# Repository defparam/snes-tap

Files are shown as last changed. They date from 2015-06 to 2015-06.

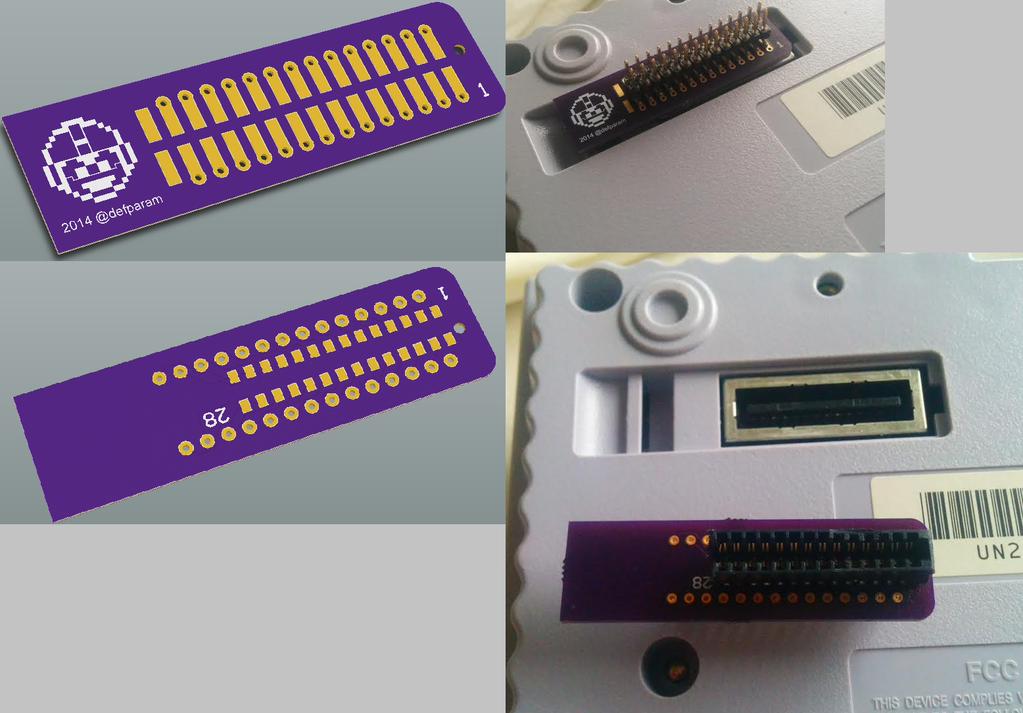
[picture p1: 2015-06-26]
photos/model_v1.0_revA.jpg

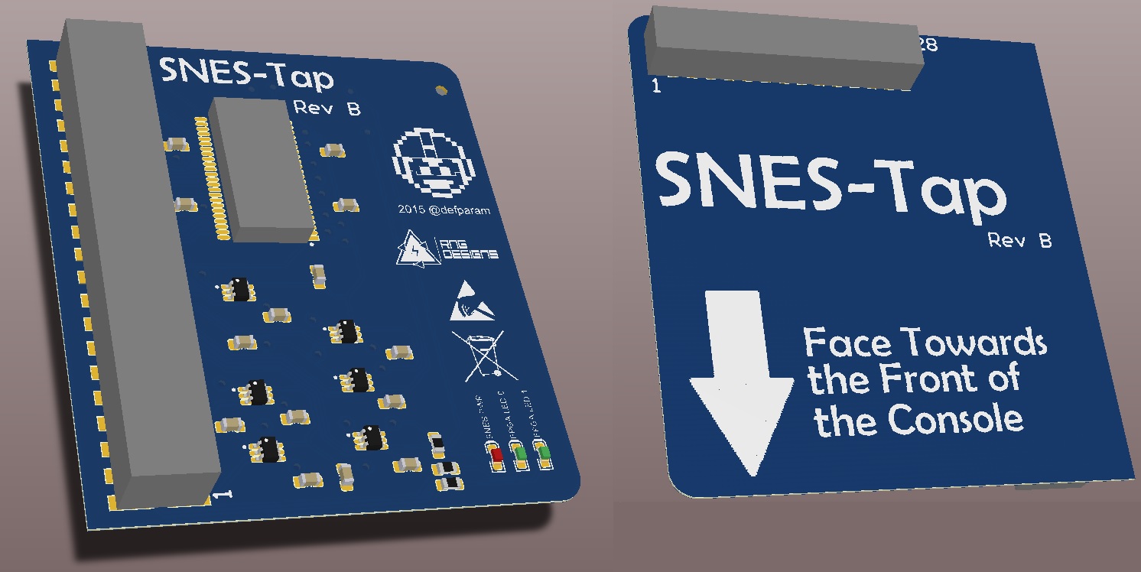
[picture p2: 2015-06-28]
photos/model_v1.2_revB.jpg

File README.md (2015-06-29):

# SNES-Tap
This project includes Altium design files for an SNES expansion port tapping board to enable FPGA snooping of the SNES console.

SNES-Tap v1.2 Rev B
---------------------------------------------------------------------
This is the second major release of this project. Drastic changes have
been made to allow for on board voltage translation support. The board
geometries have been modified to accommodate the active components and 
to interface to a 40-PIN 100mil header (instead of 30-pin in Rev A). 
The pinout of this header conforms with the GPIO 40-pin header of the 
Terasic DE0-Nano and DE0-Nano-SoC FPGA dev boards. Zipped up gerber/drill 
files have been submitted for easy fabrication direct to OSHPark 
without any DRC issues. Also included PDF schematic/layout and a 3D image
model of the board to be fabbed.

Order the board direct from OSHPark here: https://oshpark.com/shared_projects/csoqiSJ5

SNES-Tap v1.0 Rev A
---------------------------------------------------------------------
This inital version of the board design files describes a simple adapter
board that converts the SNES bottom expansion port interface to a standard
100 mil IDC header for hardware interfacing. This interface gives you access
to the data bus and the peripheral address bus of the SNES. The interface also
gives you access to analog audio channels, the reset, the interrupt pin and a
couple of clocks.

Order the board direct from OSHPark here: https://oshpark.com/shared_projects/HncHwJox

Components (Connectors)
---------------------------------------------------------------------
There are two connectors used in this board. The connector which plugs into the SNES
expansion port is a rare 2.0mm pitch micro edge connector. There aren't many vendors
which create this connector type. On this board we use the SAMTEC MEC2-30-01-L-DV.
The MEC2-30-01-L-DV is a 60-pin polarized connector, since the MEC2 doesn't have a 28-pin
variant we use the MEC2-30-01-L-DV and saw/dremel off pins 29-60. The footprint in the design
is modified to adapt to this new 28-pin footprint.

The second connector is a simple 30-pin 100 mil IDC header. In this design we used the
SAMTEC TSM-114-01-L-DV. (REV A only)

On Rev B the pin header will be 40-pin 100 mil IDC header. The part number is SAMTEC HTST-120-01-T-DV

TODO:
--------
Assemble the board, fix issues and incorporate fixed into v1.4 Rev C

-Evan

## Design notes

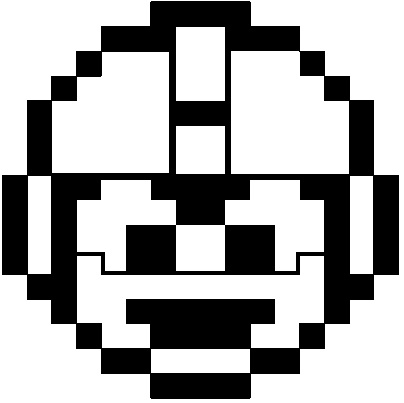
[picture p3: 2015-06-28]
photos/helmet.jpg

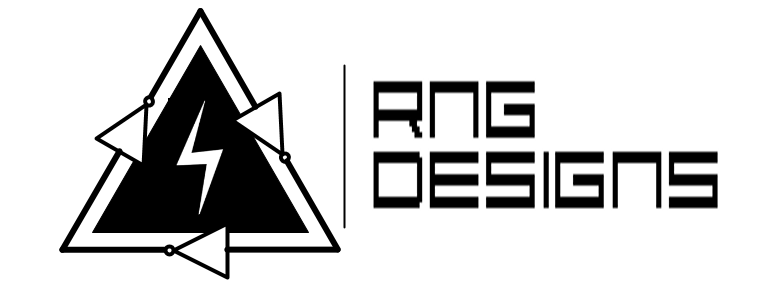
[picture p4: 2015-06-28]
photos/rngd.bmp

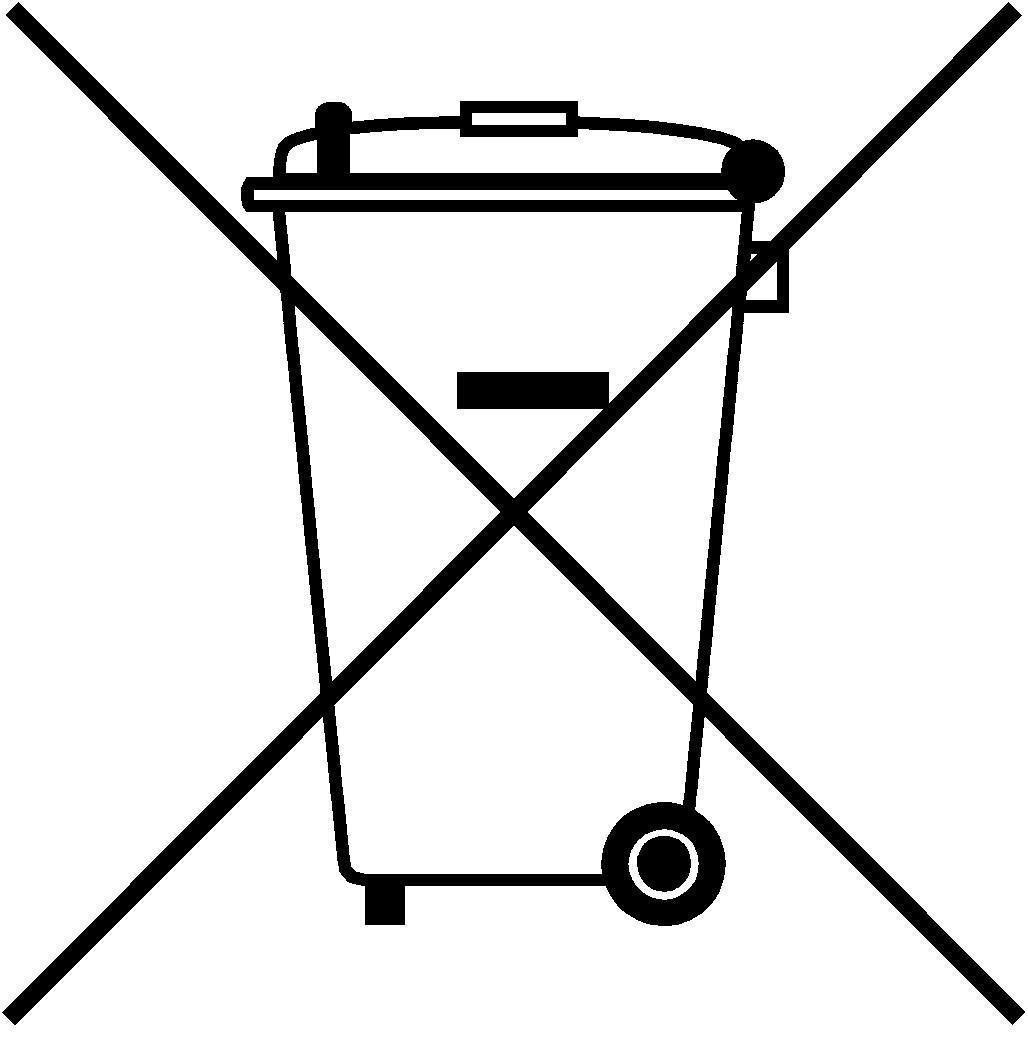
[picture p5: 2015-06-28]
photos/weee.bmp

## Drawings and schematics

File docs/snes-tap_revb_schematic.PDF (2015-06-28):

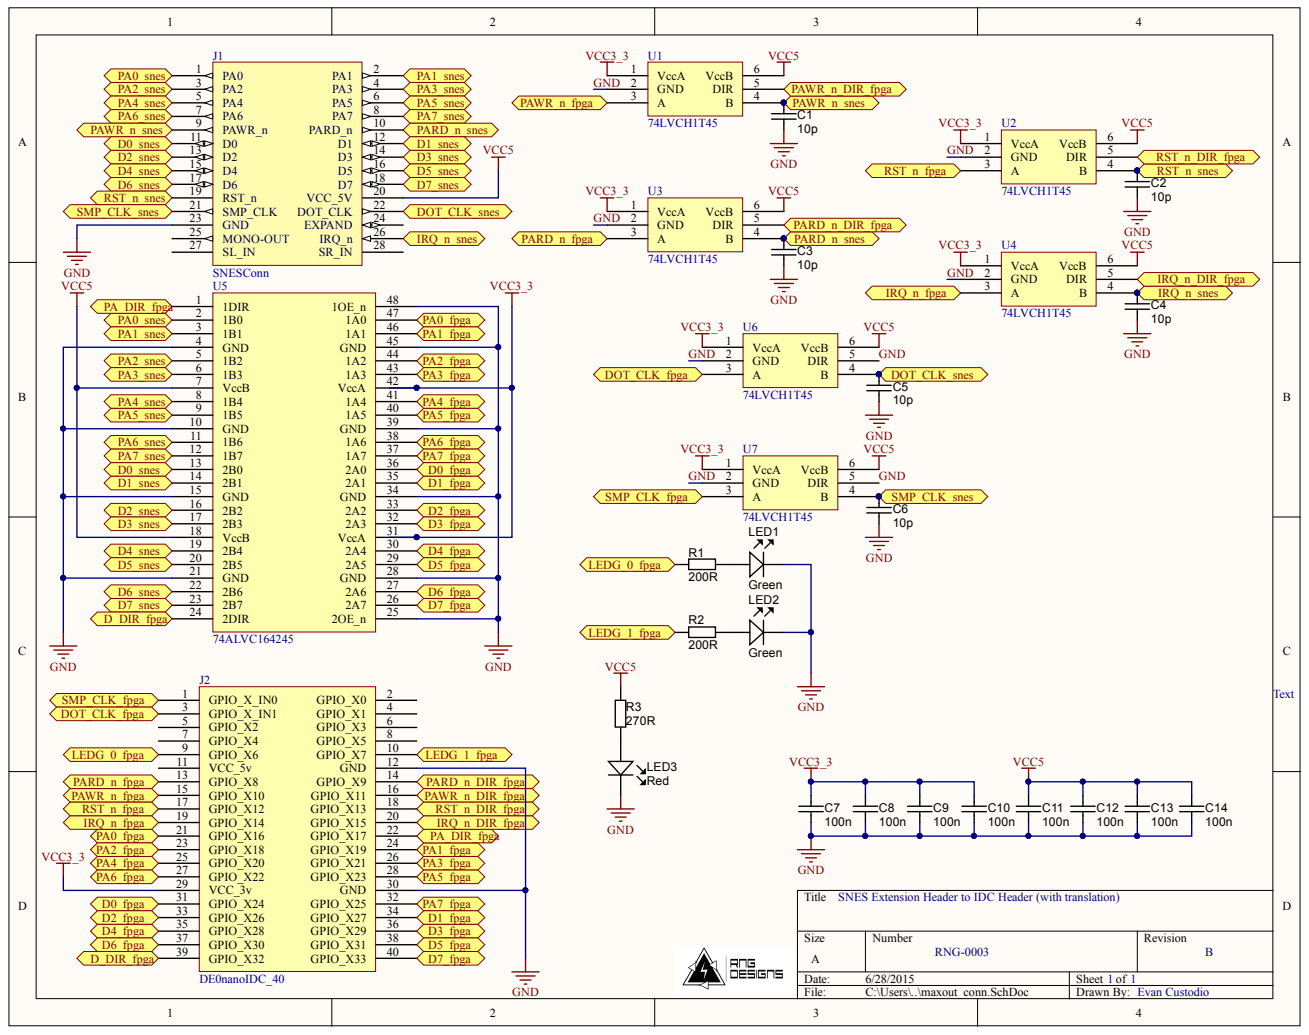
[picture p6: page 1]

1B5 9 | 25 2A7 26 2A6 27 GND 28 2A5 29 2A4 30 VccA 31 2A3 32 2A2 33 GND 34 2A1 35 2A0 36 1A7 37 1A6 38 GND 39 1A5 40 1A4 41 VccA 42 1A3 43 1A2 44 GND 45 1A1 46 1A0 47 1OE_n

PA6_snes PA7_snes D0_snes D1_snes | 1B6 11 | PA6_fpga PA7_fpga D0_fpga D1_fpga

SNES Extension Header to IDC Header (with translation)

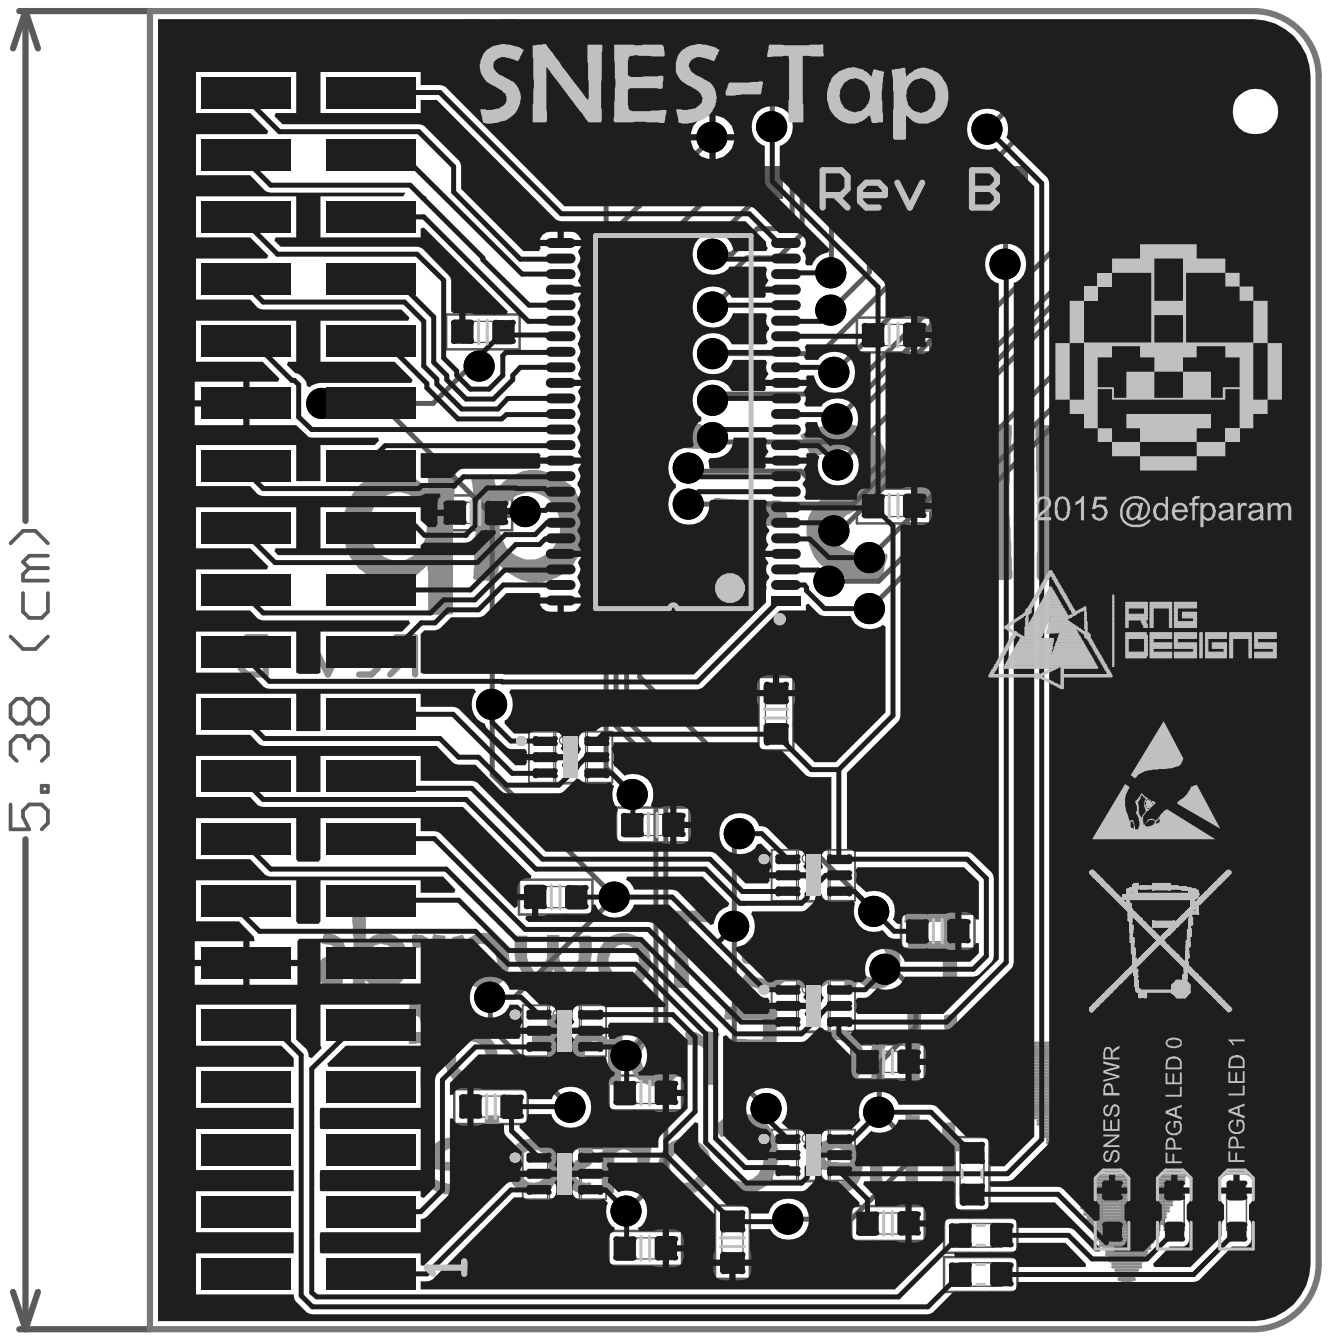
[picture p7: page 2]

# Board S

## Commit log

2015-06-26 initial checkin v1.0
    This is the initial checkin on the snes-tap board
    [SNESConn.PcbLib, SNESConn.SchLib, SNESConnIDC.PcbLib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]
2015-06-26 Revert "initial checkin v1.0"
    This reverts commit ad7a35833748aa7cc485e4c0c2509bb23b4a8a90.
    [SNESConn.PcbLib, SNESConn.SchLib, SNESConnIDC.PcbLib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]
2015-06-26 Initial Checkin
    [SNESConn.PcbLib, SNESConn.SchLib, SNESConnIDC.PcbLib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]
2015-06-26 Added connector information
2015-06-26 Updated component pinout names for the SNES connector
    [SNESConn.SchLib, maxout_conn.SchDoc]
2015-06-28 Releasing v1.2 with on board translation support
    [ActiveComp.PcbLib, ActiveComp.SchLib, SNESConn.PcbLib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]
2015-06-28 Fixed couple of typos
2015-06-28 Added OSHPark board links
